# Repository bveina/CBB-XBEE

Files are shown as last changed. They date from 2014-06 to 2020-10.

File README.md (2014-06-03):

CBB-XBEE
========

This repository contains the design files for the Logic Supply CBB-XBEE Cape for the 
BeagleBone and BeagleBone Black. It's a general prototyping cape with a footprint to connect a XBee or
other compatible radio module.

The CBB-XBEE Cape is available at http://www.logicsupply.com/components/beaglebone/capes/cbb-xbee/

Check out the CBB-XBEE manual at https://docs.google.com/document/d/1f1zFzsrbu90K2d8ETkYjHSfjAa8HdVvbnBUYrnl4jPE/edit?usp=sharing

----

Follow us on Google+ for updates and more information: https://plus.google.com/u/0/b/103613886667848850929/

Created by Alexander Hiam for Logic Supply.

This work is licensed under the Creative Commons Attribution-Share Alike 3.0 Unported License. 
To view a copy of this license, visit http://creativecommons.org/licenses/by-sa/3.0/ or send a 
letter to Creative Commons, 171 Second Street, Suite 300, San Francisco, California, 94105, USA.

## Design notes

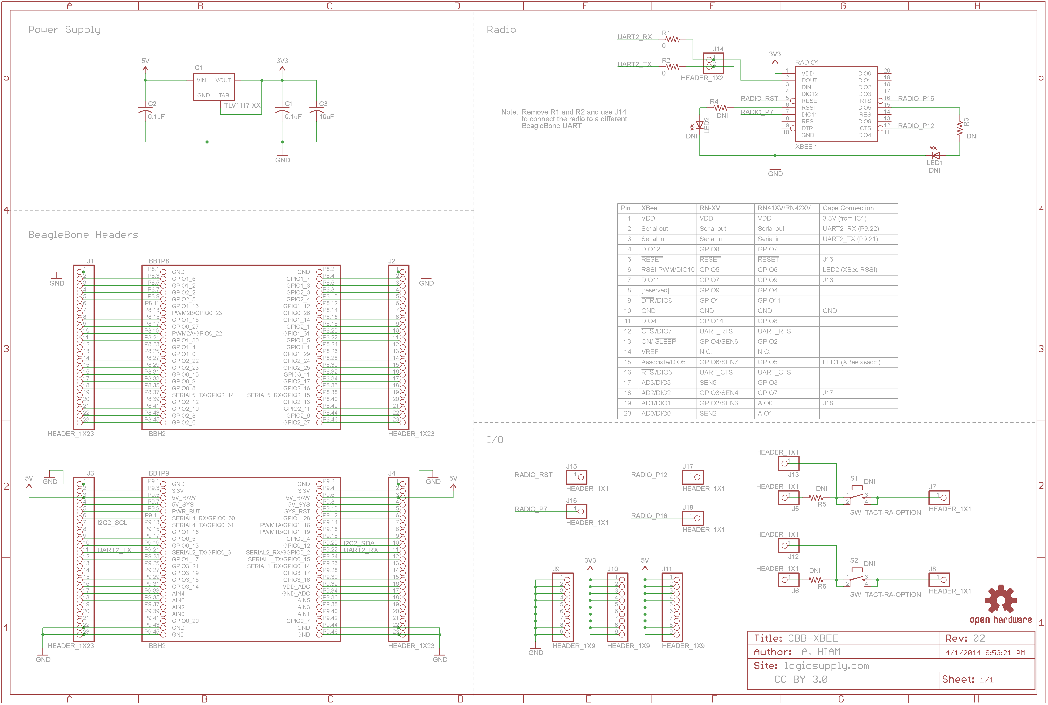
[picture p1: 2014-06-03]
CBB-XBEE-sch.png

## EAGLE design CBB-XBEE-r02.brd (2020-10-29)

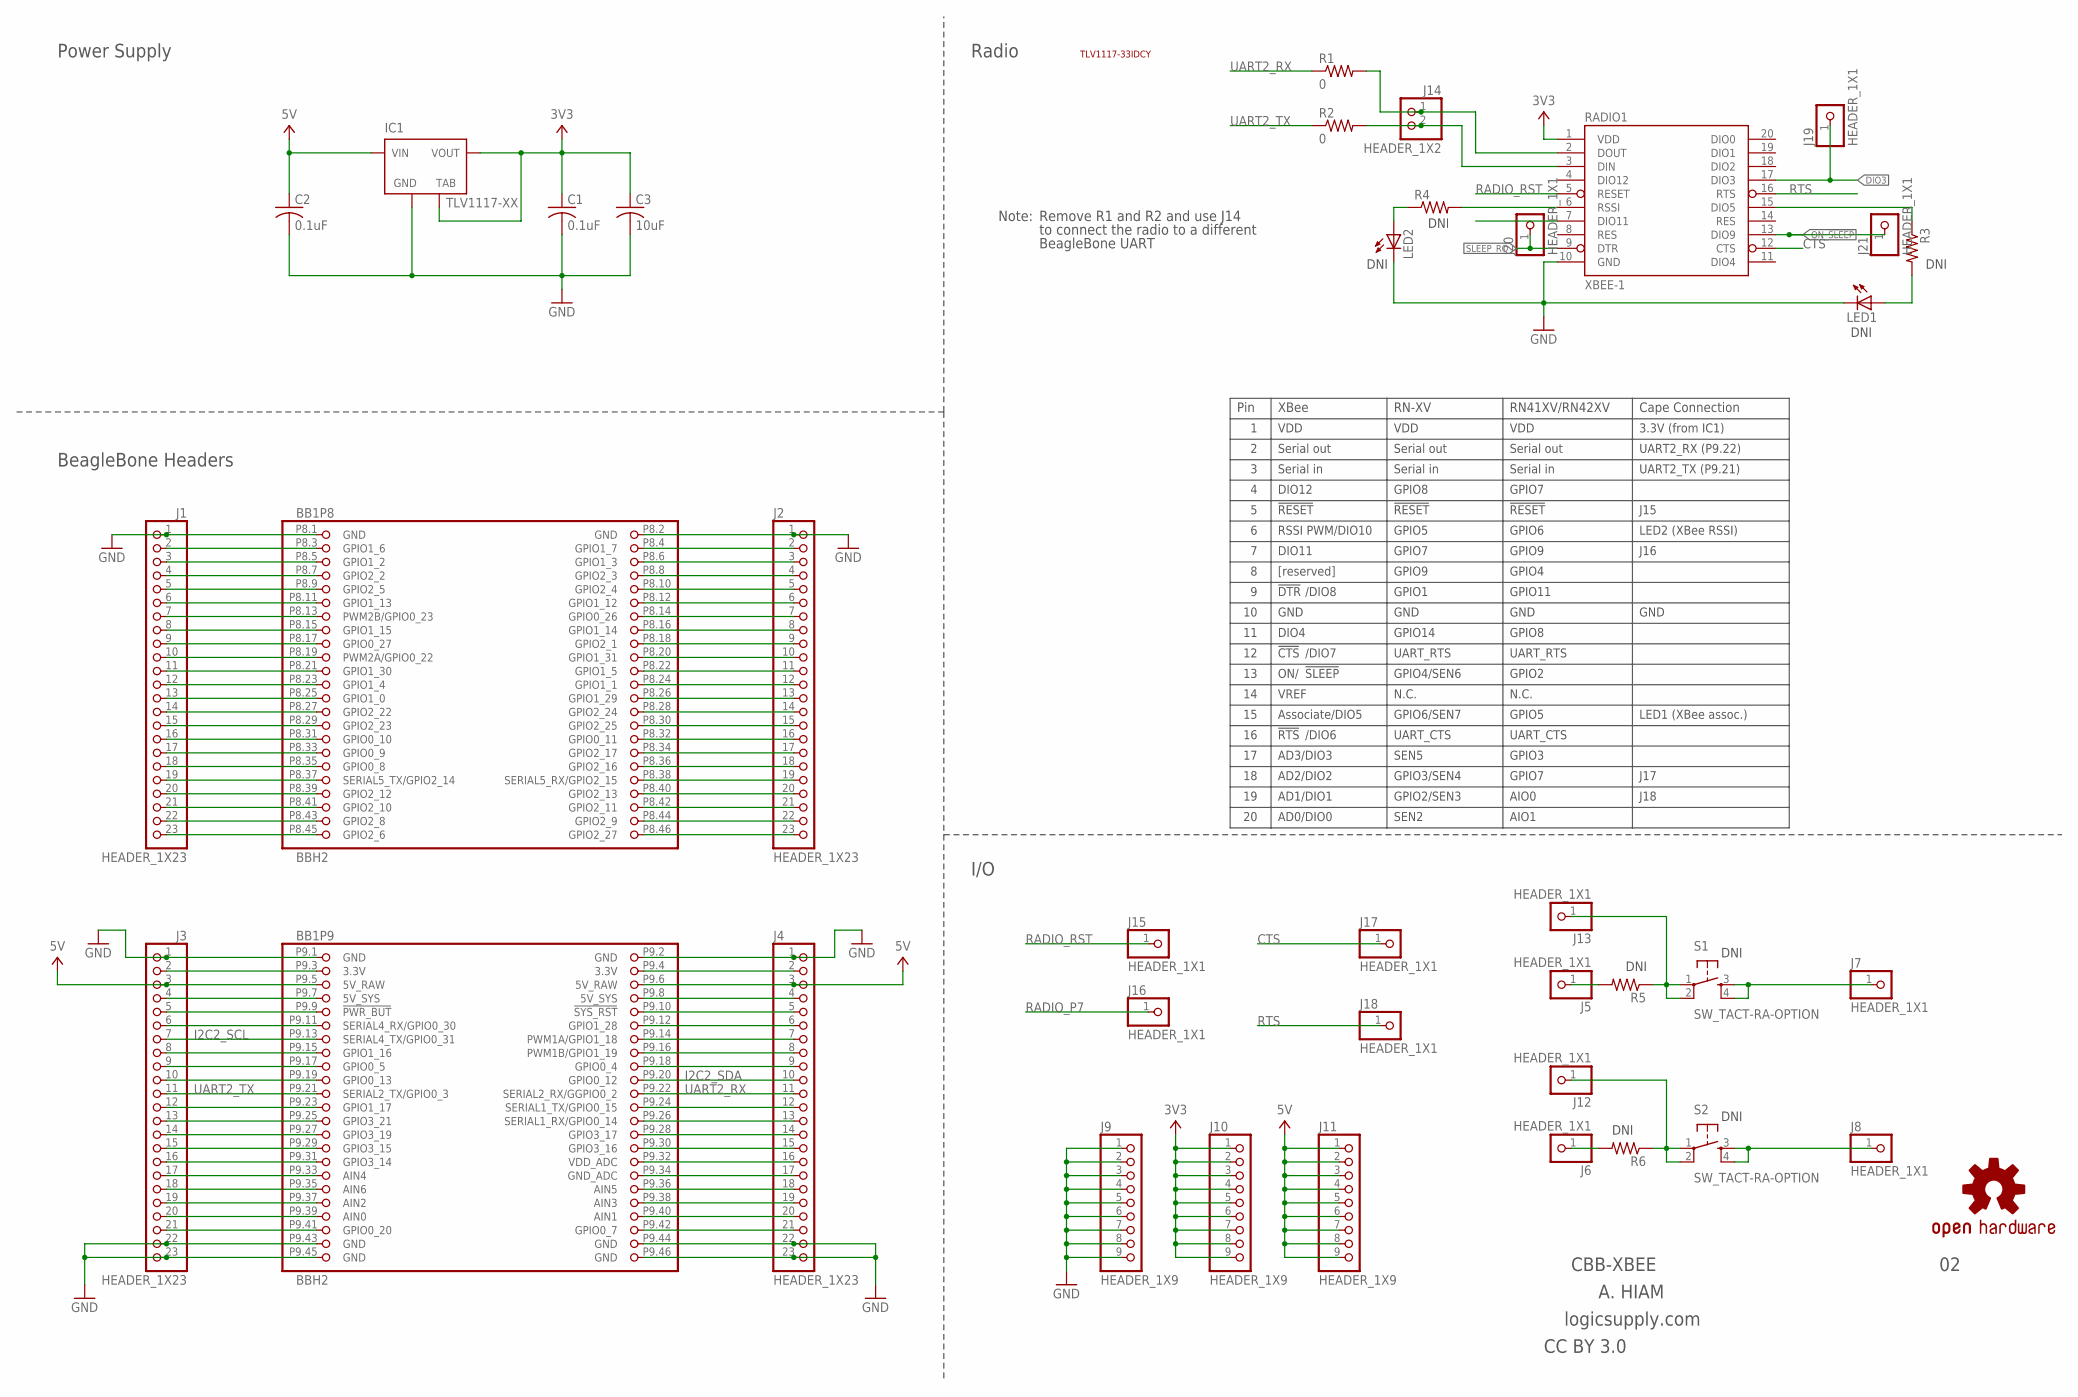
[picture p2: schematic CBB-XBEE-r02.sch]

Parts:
BB1: BBH2; BB_CAPE_TOP
C1, C2: 0.1uF; C0805
C3: 10uF; C0805
IC1: TLV1117-XX; SOT223
J1, J2, J3, J4: HEADER_1X23
J5, J6, J7, J8, J12, J13, J15, J16, J17, J18, J19, J20, J21: HEADER_1X1
J9, J10, J11: HEADER_1X9
J14: HEADER_1X2
LED1, LED2: LEDCHIPLED_0805; CHIPLED_0805
R1, R2: 0; R0805
R3, R4: R0805
R5, R6: R0207/10; 0207/10
RADIO1: XBEE-1; XBEE
S1, S2: SW_TACT-RA-OPTION; TACT-PTH-RA-OPTION
U$7: OSHW-LOGOM; OSHW-LOGO-M

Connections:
3V3: C1.1, C3.1, IC1.2 (VOUT), IC1.4 (TAB), J10.1, J10.2, J10.3, J10.4, J10.5, J10.6, J10.7, J10.8, J10.9, RADIO1.1 (VDD)
5V: BB1.P9.5 (5V_RAW), BB1.P9.6 (5V_RAW), C2.1, IC1.3 (VIN), J3.3, J4.3, J11.1, J11.2, J11.3, J11.4, J11.5, J11.6, J11.7, J11.8, J11.9
CTS: J17.1, RADIO1.12 (CTS)
DIO3: J19.1, RADIO1.17 (DIO3)
GND: BB1.P8.1 (GND), BB1.P8.2 (GND), BB1.P9.1 (GND), BB1.P9.2 (GND), BB1.P9.43 (GND), BB1.P9.44 (GND), BB1.P9.45 (GND), BB1.P9.46 (GND), C1.2, C2.2, C3.2, IC1.1 (GND), J1.1, J2.1, J3.1, J3.22, J3.23, J4.1, J4.22, J4.23, J9.1, J9.2, J9.3, J9.4, J9.5, J9.6, J9.7, J9.8, J9.9, LED1.C, LED2.C, RADIO1.10 (GND)
I2C2_SCL: BB1.P9.19 (GPIO0_13), J3.10
I2C2_SDA: BB1.P9.20 (GPIO0_12), J4.10
unnamed: BB1.P9.14 (PWM1A/GPIO1_18), J4.7
unnamed: BB1.P8.3 (GPIO1_6), J1.2
unnamed: BB1.P8.5 (GPIO1_2), J1.3
unnamed: BB1.P8.7 (GPIO2_2), J1.4
unnamed: BB1.P8.9 (GPIO2_5), J1.5
unnamed: BB1.P8.11 (GPIO1_13), J1.6
unnamed: BB1.P8.13 (PWM2B/GPIO0_23), J1.7
unnamed: BB1.P8.15 (GPIO1_15), J1.8
unnamed: BB1.P8.17 (GPIO0_27), J1.9
unnamed: BB1.P8.19 (PWM2A/GPIO0_22), J1.10
unnamed: BB1.P8.21 (GPIO1_30), J1.11
unnamed: BB1.P8.23 (GPIO1_4), J1.12
unnamed: R3.1, RADIO1.15 (DIO5)
unnamed: BB1.P9.3 (3.3V), J3.2
unnamed: BB1.P9.4 (3.3V), J4.2
unnamed: BB1.P8.25 (GPIO1_0), J1.13
unnamed: BB1.P8.27 (GPIO2_22), J1.14
unnamed: BB1.P8.29 (GPIO2_23), J1.15
unnamed: BB1.P8.31 (GPIO0_10), J1.16
unnamed: BB1.P8.33 (GPIO0_9), J1.17
unnamed: BB1.P8.35 (GPIO0_8), J1.18
unnamed: BB1.P8.37 (SERIAL5_TX/GPIO2_14), J1.19
unnamed: BB1.P8.39 (GPIO2_12), J1.20
unnamed: BB1.P8.41 (GPIO2_10), J1.21
unnamed: BB1.P8.43 (GPIO2_8), J1.22
unnamed: BB1.P8.45 (GPIO2_6), J1.23
unnamed: J13.1, R5.1, S1.1, S1.2
unnamed: BB1.P9.10 (!SYS_RST), J4.5
unnamed: R4.2, RADIO1.6 (RSSI)
unnamed: LED1.A, R3.2
unnamed: BB1.P9.16 (PWM1B/GPIO1_19), J4.8
unnamed: BB1.P9.18 (GPIO0_4), J4.9
unnamed: BB1.P9.7 (5V_SYS), J3.4
unnamed: BB1.P9.24 (SERIAL1_TX/GPIO0_15), J4.12
unnamed: BB1.P9.26 (SERIAL1_RX/GPIO0_14), J4.13
unnamed: BB1.P9.28 (GPIO3_17), J4.14
unnamed: BB1.P9.30 (GPIO3_16), J4.15
unnamed: BB1.P9.32 (VDD_ADC), J4.16
unnamed: BB1.P9.34 (GND_ADC), J4.17
unnamed: BB1.P9.36 (AIN5), J4.18
unnamed: BB1.P9.38 (AIN3), J4.19
unnamed: BB1.P9.40 (AIN1), J4.20
unnamed: BB1.P9.42 (GPIO0_7), J4.21
unnamed: J12.1, R6.1, S2.1, S2.2
unnamed: J8.1, S2.3, S2.4
unnamed: J7.1, S1.3, S1.4
unnamed: BB1.P9.8 (5V_SYS), J4.4
unnamed: J5.1, R5.2
unnamed: BB1.P9.9 (!PWR_BUT), J3.5
unnamed: BB1.P9.11 (SERIAL4_RX/GPIO0_30), J3.6
unnamed: BB1.P9.13 (SERIAL4_TX/GPIO0_31), J3.7
unnamed: BB1.P9.15 (GPIO1_16), J3.8
unnamed: BB1.P9.17 (GPIO0_5), J3.9
unnamed: J6.1, R6.2
unnamed: BB1.P9.23 (GPIO1_17), J3.12
unnamed: BB1.P9.25 (GPIO3_21), J3.13
unnamed: BB1.P9.27 (GPIO3_19), J3.14
unnamed: BB1.P9.29 (GPIO3_15), J3.15
unnamed: BB1.P9.31 (GPIO3_14), J3.16
unnamed: BB1.P9.33 (AIN4), J3.17
unnamed: BB1.P9.35 (AIN6), J3.18
unnamed: BB1.P9.37 (AIN2), J3.19
unnamed: BB1.P9.39 (AIN0), J3.20
unnamed: BB1.P9.41 (GPIO0_20), J3.21
unnamed: BB1.P8.4 (GPIO1_7), J2.2
unnamed: BB1.P8.6 (GPIO1_3), J2.3
unnamed: BB1.P8.8 (GPIO2_3), J2.4
unnamed: BB1.P8.10 (GPIO2_4), J2.5
unnamed: BB1.P8.12 (GPIO1_12), J2.6
unnamed: BB1.P8.14 (GPIO0_26), J2.7
unnamed: BB1.P8.16 (GPIO1_14), J2.8
unnamed: BB1.P8.18 (GPIO2_1), J2.9
unnamed: BB1.P8.20 (GPIO1_31), J2.10
unnamed: BB1.P8.22 (GPIO1_5), J2.11
unnamed: BB1.P8.24 (GPIO1_1), J2.12
unnamed: BB1.P8.26 (GPIO1_29), J2.13
unnamed: BB1.P8.28 (GPIO2_24), J2.14
unnamed: BB1.P8.30 (GPIO2_25), J2.15
unnamed: BB1.P8.32 (GPIO0_11), J2.16
unnamed: BB1.P8.34 (GPIO2_17), J2.17
unnamed: BB1.P8.36 (GPIO2_16), J2.18
unnamed: BB1.P8.38 (SERIAL5_RX/GPIO2_15), J2.19
unnamed: BB1.P8.40 (GPIO2_13), J2.20
unnamed: BB1.P8.42 (GPIO2_11), J2.21
unnamed: BB1.P8.44 (GPIO2_9), J2.22
unnamed: BB1.P8.46 (GPIO2_27), J2.23
unnamed: LED2.A, R4.1
unnamed: J14.2, R2.2, RADIO1.3 (DIN)
unnamed: J14.1, R1.2, RADIO1.2 (DOUT)
unnamed: BB1.P9.12 (GPIO1_28), J4.6
ON_!SLEEP: J21.1, RADIO1.13 (DIO9)
RADIO_P7: J16.1, RADIO1.7 (DIO11)
RADIO_RST: J15.1, RADIO1.5 (RESET)
RTS: J18.1, RADIO1.16 (RTS)
SLEEP_RQ: J20.1, RADIO1.9 (DTR)
UART2_RX: BB1.P9.22 (SERIAL2_RX/GGPIO0_2), J4.11, R1.1
UART2_TX: BB1.P9.21 (SERIAL2_TX/GPIO0_3), J3.11, R2.1

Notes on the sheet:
CBB-XBEE
A. HIAM
BeagleBone Headers
CC BY 3.0
XBee
RN-XV
RN41XV/RN42XV
Pin
VDD
GND
Serial out
Serial in
Cape Connection
3.3V (from IC1)
DIO12
!RESET
RSSI PWM/DIO10
DIO11
[reserved]
!DTR
/DIO8
DIO4
!CTS
!RTS
/DIO7
/DIO6
VREF
ON/
!SLEEP
Associate/DIO5
AD3/DIO3
AD2/DIO2
AD1/DIO1
AD0/DIO0
GPIO8
GPIO5
GPIO7
GPIO9
GPIO1
GPIO14

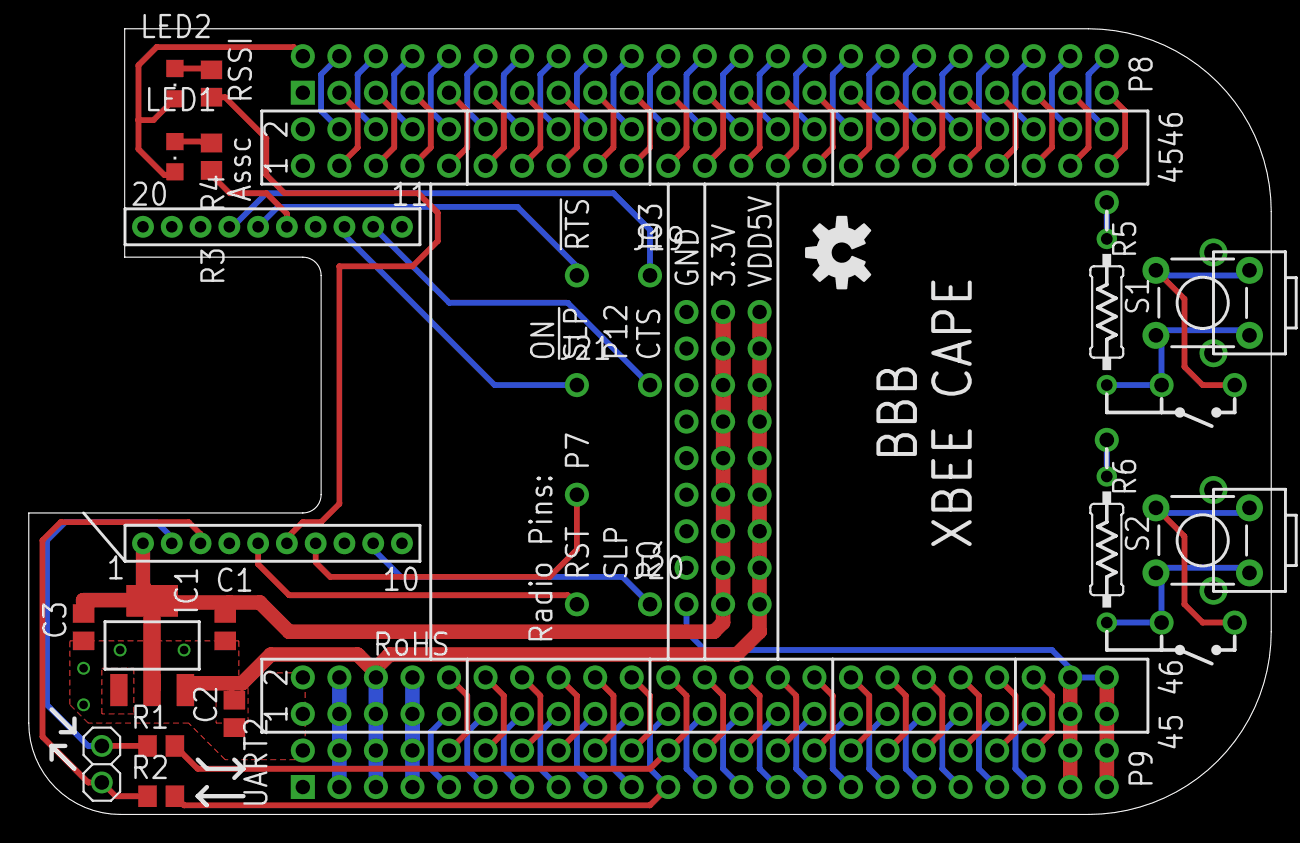
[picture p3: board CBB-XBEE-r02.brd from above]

Board: 2 copper layers, 86.4 x 54.6 mm, 38 parts (1 on the bottom side), 104 nets.

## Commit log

2014-06-03 added schematic
2016-06-06 Uploaded Eagle files
    [CBB-XBEE-r02.brd, CBB-XBEE-r02.sch]
2020-10-29 modified layout to include extra test points for series 3 xbees.
    [CBB-XBEE-r02.brd, CBB-XBEE-r02.sch]
